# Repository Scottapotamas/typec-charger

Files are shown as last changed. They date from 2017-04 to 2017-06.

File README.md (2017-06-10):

# typec-charger
USB Type C charger for laptops or phones, that uses generic DC inputs as the source.

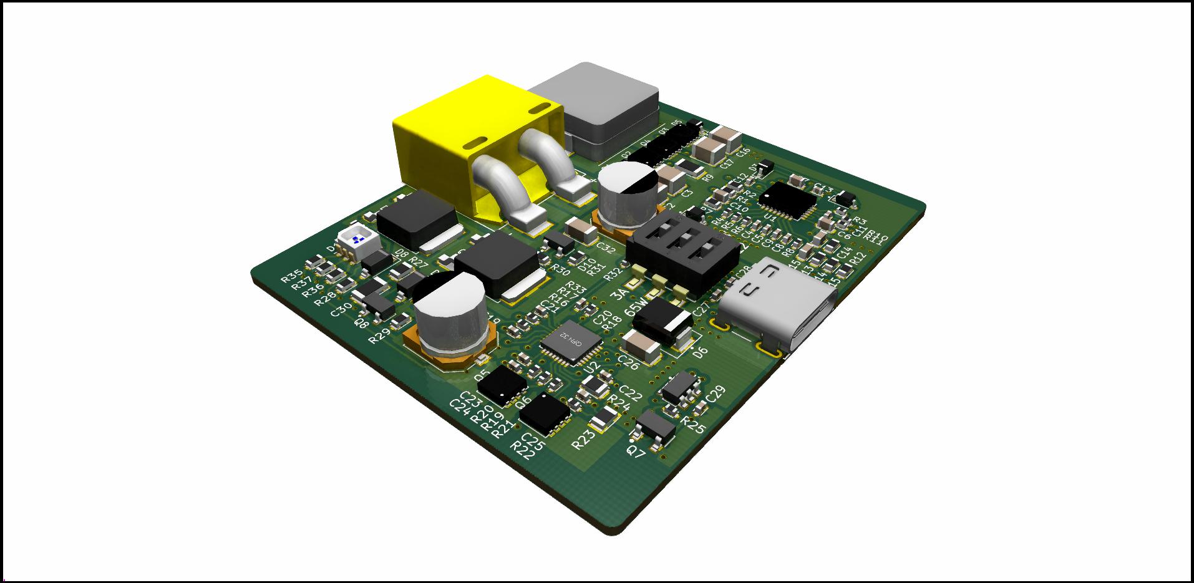
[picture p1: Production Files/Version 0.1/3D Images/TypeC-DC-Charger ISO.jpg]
PCB Iso


# Requirements & Goals

Create a DC-DC charger that uses USBc PD as the delivery mechanism. 
Aim to support the widest range of devices possible (including my Dell XPS 9550).

Run off Li-Poly or Li-Ion cells or similar sources. This could include car batteries (directly or from cigarette lighter socket), and other sources. 
This is useful when taking devices to the field, or allows a comodity pouch cell battery to act as a bulk battery bank.
 
- Accept wide input range sources, 10V to 26V operating input (3S to 6S lithium, includes 12V and 24V automotive).
- Use XT60? input to allow direct lipo connectors or existing COTS cables with aligators etc.

- Input must be ESD protected and filtered.
- Input must have reverse polarity protection, and overvoltage up to 30V DC.
- Device must indicate that a power source has been applied.
- Device should include visual indication that battery is low.
- Device should include battery voltage low-cutoff to prevent over-discharge of source.

- Output USB 3.1 C Power Delivery 2.0 Compliant charging power (5, 9, 12, 20V) at up to 3A. Consider 5A as optional expansion?
- USB Type C socket on the charger, to allow users to find their own cable. No integrated cable tail.
- Compatibility with Dell XPS, Apple Macbook Pro, and other devices.
- Compatibility with USB-C fast charging phones if possible.
- Compatiblity with USB2 charging devices as part of compatibility mode (via 3.1C -> 2.0 MicroB cable).
- It is desirable that the charger supports greater than 60W charging for faster charge on performance laptops.
- Output should be ESD Protected and feature filtering for EMI.

- Where practical, x/y/z dimensions should be minimised for tight form factor.
- The device's enclosure should not exceed 50C at steadystate for a 'full load'.
- The device should not emit any audible noice (coil whine etc) which can be heard in a quite space (<25dB?)
- The product should aim to meet applicable EMC standards (class 2, non-intentional radiator), use spec analyser at work to validate.

Ideally this solution costs less than $100AU (not including charge cable or batteries). This would price it under or around the Apple 61W and 87W chargers, or the Chromebook Pixel 60W charger after importing to AUS. 

- Manufacturing cost of assembled PCB is less than $60USD.
- Manufacturing cost of enclosure less than $20USD.
- Manufacturing cost of packaging (box, manual, etc) less than $5USD.

# Testing and Implementation Notes

- Wide input power supply low voltage cutoff set at just under 9V. This is the extent of low battery protection, not using anything smarter.
- Currently there is no additional 3 or 5V reg, which means there isn't any stable voltage. Any additional circuitry has to either support 5-20V or include regulation.
- Input protection circuit is beefy. Confidence in the charger is important, especially with all the press going on with USBC non-compliant chargers.
- Battery indication led was really hard to get worked out. Uses a SMD led and lightpipe for charging status. Might remove this for production.
- Board has been made as small as possible to fit in the example extrusion.
- Power dissipation for power supply stage is worst case 1.7W between all parts. Worst part is switching fet at 650mW. Consider heatsink or thermal transfer to case?
- Validate thermal performance with thermal camera.
- XT60 connector is too high for normal mounting. Consider using a second PCB to drop the height to the center of the extrusion or a different connector.
- Greater than 3A is supported with switch.
- Power limit set to ~60W default, switch will allow ~90W.
- 5A is possible to be selected without the 90W expansion (5/12V devices)

# Manufacturability

- Board is a 4 layer pcb with single sided population. All parts are SMD.
- Small form factor means small boxes and packaging requirements.
- Consider enclosures 
	- https://www.aliexpress.com/store/product/4-pcs-electronics-aluminum-enclosure-boxes-13-60-50mm-2015-aluminum-powder-coating-project-box-aluminum/1006252_32312473247.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
	- https://www.aliexpress.com/item/1-piece-szomk-aluminum-project-box-100-60-13mm-enclosures-for-electronics-electronic-2014-new-aluminum/32241037210.html

5 Prototype boards have been ordered for PCBA. Cost per board is just under 60USD at current.

# Device Compatibility

- Dell XPS didn't like negotiation stage where eval board sat at 12V for a few hundred milliseconds. Disabling 12V and going from 5->20V works fine.
- Investigate XPS when the 5V and 20V are done by same regulator instead of two-stage.
- Dell XPS will charge on lower currents as long as the charger is advertising at least 60W.
- Haven't been able to get more than 61W draw from the XPS, regardless of BIOS settings.

- Nintendo Switch uses the 15V standard which the main model of this charger is not designed for.
- The Switch will charge with 5V 3A though.
- People in https://www.reddit.com/r/NintendoSwitch/comments/5x948s/answering_your_questions_about_usb_typec/ say that the Switch uses 12V as fallback from 15V.

- Supports BC1.2 charging for legacy USB2 devices at up to 2A.
- Charges phones fine at 10W over a USBC-MicroB cable.
- Should support most phones properly with 5V 3A charging over TypeC.

# Sale Notes

Sell it as a standalone device with the option of adding the following:

- Barrel to XT60 connector
- Barrel to Aligator clips
- Barrel to cigarette lighter
- Barrel to D-Tap
- Barrel to ring terminals?

Device should also include some packaging and a card describing the specifications etc.

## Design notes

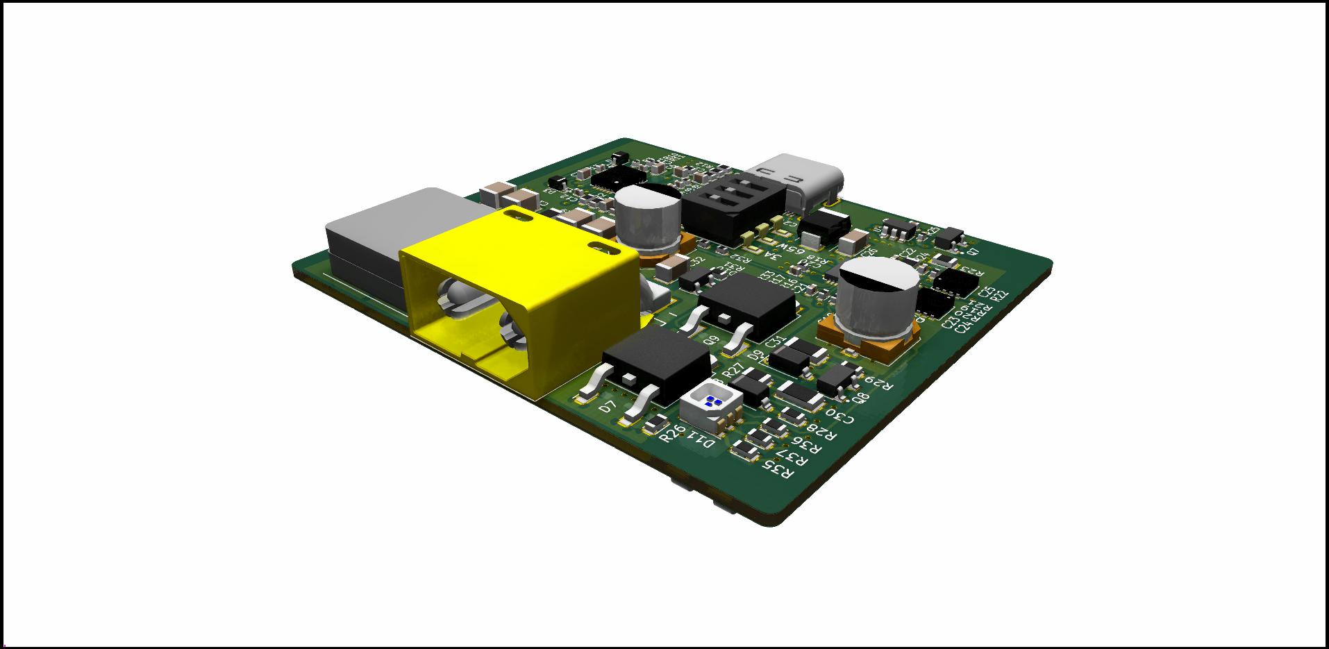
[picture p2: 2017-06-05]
Production Files/Version 0.1/3D Images/TypeC-DC-Charger POWERISO.jpg

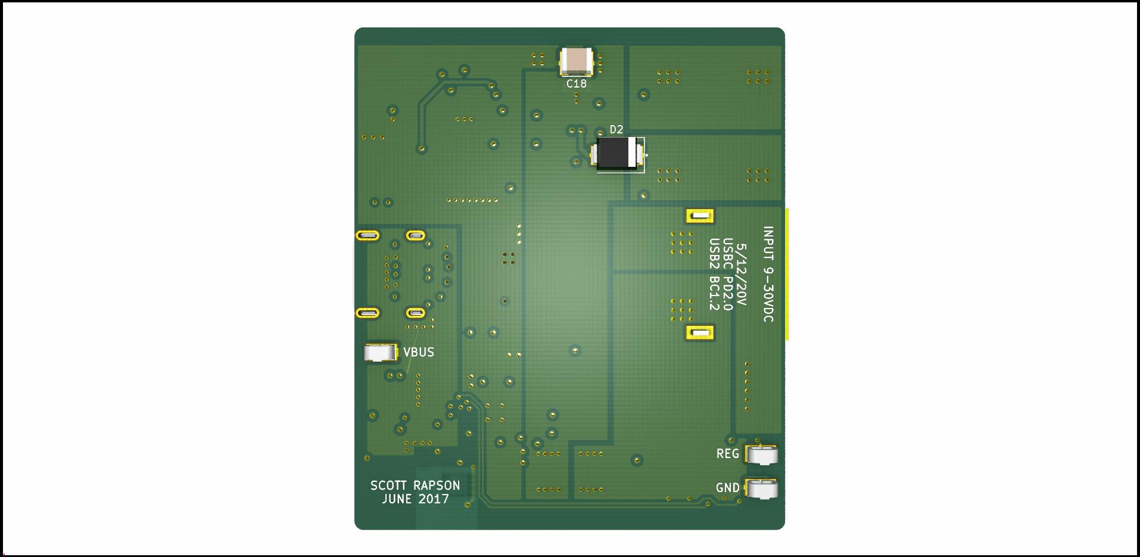
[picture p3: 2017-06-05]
Production Files/Version 0.1/3D Images/TypeC-DC-Charger BOTTOM.jpg

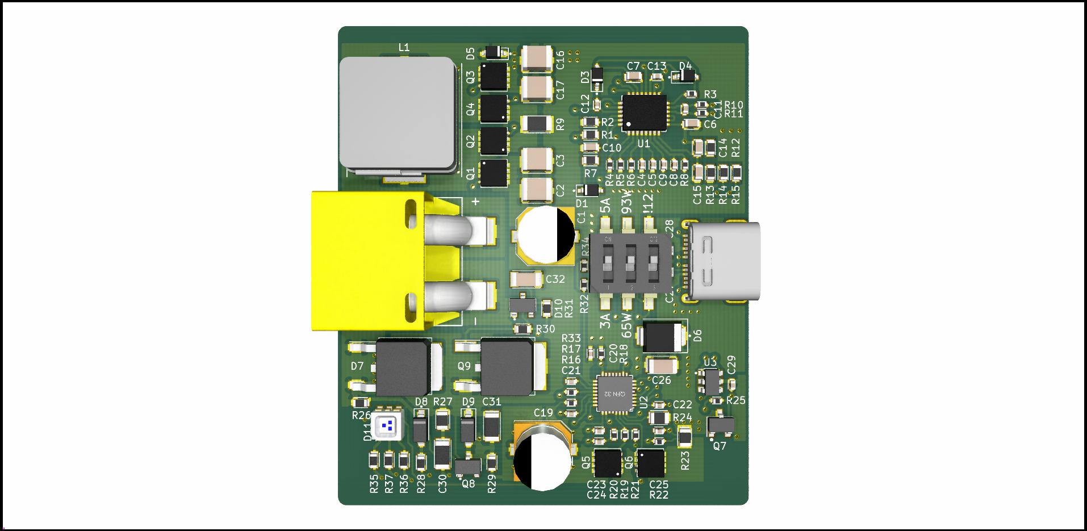
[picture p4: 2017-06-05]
Production Files/Version 0.1/3D Images/TypeC-DC-Charger TOP.jpg

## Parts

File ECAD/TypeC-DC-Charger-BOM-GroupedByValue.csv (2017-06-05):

Title:
Rev:
Source: | C:/Projects/typec-charger/ECAD/TypeC-DC-Charger.sch
Date: | 6/5/2017 10:23:57 AM
Component Count: | 99
Ref | Qty | Value | Description | Manf | Manf# | Installed | Footprint
C1, C19 | 2 | 100UF_ELEC_35V_660X580M | CAP, ALU ELEC, 100UF, 35V, SMD | PANASONIC | EEEFT1V101AP |  | CAPAE660X580DD180L260L
C10, C15 | 2 | 100NF_X7R_1608M | CAP, MLCC, X7R, 100NF, 50V, 0603 | KEMET | C0603C104K5RACAUTO |  | CAPC1608X90L
C11 | 1 | 47PF_X7R_1005M | CAP, MLCC, X7R, 47PF, 50V, C0G, 0402, 1005M | MULTICOMP | MC0402N470K500CT |  | CAPC1005X60L
C14 | 1 | 22NF_X7R_1608M | CAP, MLCC, X7R, 22NF, 50V, 0603, 1608M | MULTICOMP | MC0603B223K500CT |  | CAPC1608X90L
C16, C17, C18 | 3 | 22UF_X7R_3225M | CAP, MLCC, X7R, 22UF, 25V, 10%, 1210, 3225M | MURATA | C1210C226K3RACTU |  | CAPC3225X170L
C2, C3 | 2 | 10UF_X7S_3225M | CAP, MLCC, X7R, 10UF, 50V, 1210 3225M | TDK | C3225X7S1H106M250AB |  | CAPC3225X170L
C20, C25 | 2 | 330NF_X5R_1005M | CAP, MLCC, X5R, 330NF, 25V, 0402, 1005M | TDK | C1005X5R1E334K050BB |  | CAPC1005X60L
C24 | 1 | 10NF_X7R_1005M | CAP, MLCC, X7R, 10NF, 50V, 0402, 1005M | KEMET | C0402C103K5RACTU |  | CAPC1005X60L
C26 | 1 | 6.8UF_X7R_3216M | CAP, MLCC, X7R, 6.8UF, 25V, 1206, 3216M | TDK | C3216X7R1E685K160AB |  | CAPC3216X135L
C27, C28 | 2 | 330PF_X7R_1005M | CAP, MLCC, X7R, 330PF, 50V, 0402, 1005M | MURATA | GRM155R71H331KA01D |  | CAPC1005X60L
C30, C31 | 2 | 1UF_X7R_3216M | CAP, MLCC, X7R, 1UF, 100V, 1206, 3216M | TDK | C3216X7R2A105K160AA |  | RESC3216X60L
C32 | 1 | 100NF_X7R_3216M | CAP, MLCC, X7R, 100nF, 100V, 1206, 3216M | YAGEO | CC1206KKX7R0BB104 |  | CAPC3216X135L
C4, C8 | 2 | 100PF_C0G_1005M | CAP, MLCC, X7R, 100PF, 50V, 0402, 1005M | MURATA | GCM1555C1H101JA16D |  | CAPC1005X60L
C5, C12, C13, C21, C22, C23, C29 | 7 | 100NF_X7R_1005M | CAP, MLCC, X7R, 100NF, 50V, 0402, 1005M | TDK | CGA2B3X7R1H104K050BB |  | CAPC1005X60L
C6, C7 | 2 | 1UF_X7R_1608M | CAP, MLCC, X7R, 1UF, 50V, 0603 | MURATA | GRM188R61H105KAALD |  | CAPC1608X90L
C9 | 1 | 22NF_X7R_1005M | CAP, MLCC, X7R, 22NF, 50V, 0402, 1005M | MURATA | GRM155R71H223KA12D |  | CAPC1005X60L
CON1 | 1 | XT60-PT-MALE | XT60PT, 3.5mm Banana Connector Style, Plug, Male, SMD | AMASS | XT60PT-M |  | XT60-PT-MALE
D1, D3, D4, D5 | 4 | 40V_500mA_SOD323 | DIODE SCHOTTKY 40V 500MA 470mV Fwd SOD323 | NXP | PMEG4005AEA |  | SOD2512X110L
D10 | 1 | BAV99 | DIODE DUAL, 100V, 215mA, 4ns, SOT23 | NXP | BAV99 |  | SOT95P240X110-3L16L
D11 | 1 | LED_RGB_PLCC6 | LED RGB, Osram Opto LRTB GFTM, 470 / 528 / 625 nm, PLCC 6, Rectangle Lens SMD package | OSRAM Opto Semiconductors | LRTB GFTM |  | PLCC110P330X340X200-8L
D2 | 1 | CD214B-B250LF | DIODE, CHIP, 50V, 2A, DO-214AA | BOURNS | CD214B-B250LF |  | SODFL5436X262L
D6 | 1 | SSB44-E3/52T_DO214AA | DIODE, Schottky, 40V, 4A, 10ns, SMB, DO-214AA | VISHAY | SSB44-E3/52T |  | SODFL5436X262L
D7 | 1 | 300V_10A_DPAK | DIODE, 10A cont, 20A, 300V, 13ns, 0.9V, DPAK | ST | STTH1003SBY-TR |  | TO440P972X240-3N
D8, D9 | 2 | 33V_500mW_SOD123 | DIODE, Zener 33V, 500mW, SOD123 | VISAY SEMICONDUCTOR | BAT41ZFILM |  | SOD3715X145L
J1 | 1 | USB_C_SOCKET_RA_SMD | USB Type C Recep, Female, R/A, TOPMNT, GLD Flash, 24 contact, 5A | Molex | 105450-0101 |  | MOLEX-105450-0101
L1 | 1 | 3.3uH_5050M | IHLP5050EZ, INDUCTOR, 3.3UH, 15A, Shielded, 0.0092ohm, 20%, | VISHAY | IHLP5050EZER3R3M01 |  | INDM132129X500N
Q1, Q2 | 2 | CSD18543Q3A | POWER MOSFET, N-CH, NexFET, 60Vds, 20Vgs, 35A, 8.1mOhm, 1.7nC gd, 2.0Vgs, SON | TI | CSD18543Q3A |  | SON65P315X300X90-9T174X245L
Q3, Q4 | 2 | CSD17551Q3A | POWER MOSFET, N-CH, NexFET, 30Vds, 20Vgs, 20A, 7.8mOhm, 1.5nC gd, 1.6Vgs, SON | TI | CSD17551Q3A |  | SON65P315X300X90-9T174X245L
Q5, Q6 | 2 | CSD17579Q3A | POWER MOSFET, N-CH, NexFET, 30Vds, 20Vgs, 20A, 8.7mOhm, 1.2nC gd, 1.5Vgs, SON | TI | CSD17579Q3A |  | SON65P315X300X90-9T174X245L
Q7 | 1 | 2N7002P | MOSFET N-CH 60V 0.36A SOT-23 | Fairchild | 2N7002,215 |  | SOT95P240X110-3L16N
Q8 | 1 | BC857B | Transistor, PNP 45V, 100mA, 250mW, SOT23 | MULTICOMP | BC857B |  | SOT95P240X110-3L16L
Q9 | 1 | IRFR9024NTRPBF | MOSFET P-CH 55V 11A DPAK TO-252AA | Infineon | IRFR9024NTRPBF |  | DPAK4P229_990X239L159X95L
R1 | 1 | 249K_1608M | RESISTOR, THICK FILM, 249K, 100mW, 1%, 0603, 1608M | VISHAY | CRCW0603249KFKEA |  | RESC1608X50L
R10, R11 | 2 | 100R_1005M | RESISTOR, THICK FILM, 100R, 63mW, 1%, 0402, 1005M | VISHAY | CRCW0402100RFKED |  | RESC1005X40L
R12 | 1 | 49K9_1608M | RESISTOR, THICK FILM, 49.9K, 100mW, 1%, 0603, 1608M | VISHAY | CRCW060349K9FKEA |  | RESC1608X50L
R13 | 1 | 9K53_1608M | RESISTOR, THICK FILM, 9.53K, 100mW, 1%, 0603, 1608M | VISHAY | CRCW06039K53FKEA |  | RESC1608X50L
R14 | 1 | 4K99_1608M | RESISTOR, THICK FILM, 4.99K, 100mW, 1%, 0603, 1608M | VISHAY | MCT06030C4991FP500 |  | RESC1608X50L
R15 | 1 | 5K76_1608M | RESISTOR, THICK FILM, 5.76K, 100mW, 1%, 0603, 1608M | PANASONIC | ERJ3EKF5761V |  | RESC1608X50L
R16 | 1 | 1M_1005M | RESISTOR, THICK FILM, 1MOhm, 63mW, 1%, 0402, 1005M | VISHAY | CRCW04021M00FKED |  | RESC1005X40L
R17 | 1 | 680K_1005M | RESISTOR, THICK FILM, 680K, 100mW, 1%, 0402, 1005M | PANASONIC | ERJ2RKF6803X |  | RESC1005X40L
R18 | 1 | 100K_1005M | RESISTOR, THICK FILM, 100K, 100mW, 1%, 0402, 1005M | PANASONIC | ERJ2RKF1003X |  | RESC1005X40L
R19, R21, R22, R25 | 4 | 10R_1005M | RESISTOR, THICK FILM, 10R, 63mW, 1%, 0402, 1005M | VISHAY | CRCW040210R0FKED |  | RESC1005X40L
R2 | 1 | 41K2_1608M | RESISTOR, THICK FILM, 41.2K, 200mW, 0603, 1608M | PANASONIC | ERJP03F4122V |  | RESC1608X50L
R20 | 1 | 1K_1005M | RESISTOR, THICK FILM, 1K, 63mW, 1%, 0402, 1005M | VISHAY | CRCW04021K00FKED |  | RESC1005X40L
R23 | 1 | 0.005R_2012M | RESISTOR, THICK FILM, 5mOhm, 500mW, 1%, 0805, 2012M | WALSIN | WW08RR005FTL |  | RESC2012X50L
R24 | 1 | 120R_2012M | RESISTOR, THICK FILM, 120R, 500mW, 5%, 0805, 2012M | PANASONIC | ERJ-P06J121V |  | RESC2012X50L
R26 | 1 | 100K_1608M | RESISTOR, THICK FILM, 100K, 125mW, 1%, 0603, 1608M | MULTICOMP | MC0063W06035100K |  | RESC1608X50L
R27 | 1 | 10R_2012M | RESISTOR, THICK FILM, 10R, 125mW, 1%, 0805, 2012M | PANASONIC | ERJ8ENF10R0V |  | RESC2012X50L
R28 | 1 | 22K_1608M | RESISTOR, THICK FILM, 22K, 100mW, 1%, 0603, 1608M | MULTICOMP | MCMR06X2202FTL |  | RESC1608X50L
R29 | 1 | 332K_1608M | RESISTOR, THICK FILM, 332K, 250mW, 0603, 1608M | PANASONIC | ERJPA3F3323V |  | RESC1608X50L
R3, R8 | 2 | 10K_1005M | RESISTOR, THICK FILM, 10K, 63mW, 1%, 0402, 1005M | VISHAY | CRCW040210K0FKED |  | RESC1005X40L
R31 | 1 | 10K0_1608M | RESISTOR, THICK FILM, 10K, 125mW, 1%, 0603, 1608M | TE CONNECTIVITY | CRGH0603F10K |  | RESC1608X50L
R32, R34 | 2 | 220K_1005M | RESISTOR, THICK FILM, 220K, 63mW, 1%, 0402, 1005M | MULTICOMP | MC00625W04021220K |  | RESC1005X40L
R33 | 1 | 0R_1005M | RESISTOR, THICK FILM, 0R, 63mW, 1%, 0402, 1005M | VISHAY | CRCW04020000Z0ED |  | CAPC1005X60L
R35 | 1 | 1K50_1608M | RESISTOR, THICK FILM, 1K5, 100mW, 1%, 0603, 1608M | MULTICOMP | MCSR06X1501FTL |  | RESC1608X50L
R36 | 1 | 2K40_1608M | RESISTOR, THICK FILM, 2K4, 63mW, 1%, 0603, 1608M | MULTICOMP | MC0063W060312K4 |  | RESC1608X50L
R37 | 1 | 330R_1608M | RESISTOR, THICK FILM, 330R, 100mW, 1%, 0603, 1608M | VISHAY DRALORIC | CRCW0603330RFKEA |  | RESC1608X50L
R4 | 1 | 93K1_1005M | RESISTOR, THICK FILM, 93.1K, 100mW, 1%, 0402, 1005M | PANASONIC | ERJ2RKF9312X |  | RESC1005X40L
R5 | 1 | 0R_1005M | RESISTOR, THICK FILM, 0R, 63mW, 1%, 0402, 1005M | VISHAY | CRCW04020000Z0ED |  | RESC1005X40L
R6 | 1 | 84K5_1005M | RESISTOR, THICK FILM, 84.5K, 63mW, 1%, 0402, 1005M | PANASONIC | ERA2AEB8452X |  | RESC1005X40L
R7, R30 | 2 | 10R_1608M | RESISTOR, THICK FILM, 10R, 125mW, 0603, 1608M | MULTICOMP | MCHP03W8F100JT5E |  | RESC1608X50L
R9 | 1 | 0.01R_3216M | RESISTOR, THICK FILM, 10mOhm, 1W, 1206, 3216M | Vishay | WSLP1206R0100FEA |  | RESC3216X60L
SW1 | 1 | 2.54mm_3xSPST_SMD | DIP/SIP Switch, 3 Circuits, SPST, SMD, DIP Sealed, 24 VDC | MULTICOMP | MCEMR-03-T |  | MCEMR-03-T
TEST2, TEST3, TEST5 | 3 | PROBE_HOOK | PCB Probe Hook SMD | HARWIN | S1751-46R |  | HARWIN_S1751-46
U1 | 1 | LM5175RHF | 4-Switch Synchronous Buck-Boost Controller, 3.5-42V IN, 0.8-55V OUT, <600kHz, VQFN-28 | TEXAS INSTRUMENTS | LM5175RHFR |  | QFN50P500X400X100-29T255X355N
U2 | 1 | TPS25741 | USB 3.1 Type C and USB PD 2.0 Delivery Port Control IC, 5/12/20V 15-100W, internal 1.8V 35mA, QFN 32 with pad | TEXAS INSTRUMENTS | TPS24741 |  | QFN40P400X400X100-33T280N
U3 | 1 | TPS2514 | TPS251xx USB, Dedicated Charging Port Controller, BC1.2 auto detect, SOT23-6 | TI | TPS2514DBVR |  | SOT95P240X110-6L16L
Tool: | Eeschema (2016-11-21 revision f7cc0a9)-makepkg
Script: | C:\Projects\ECAD\kicad-scripts\BOM\bom\BOM-GroupedByValue.py

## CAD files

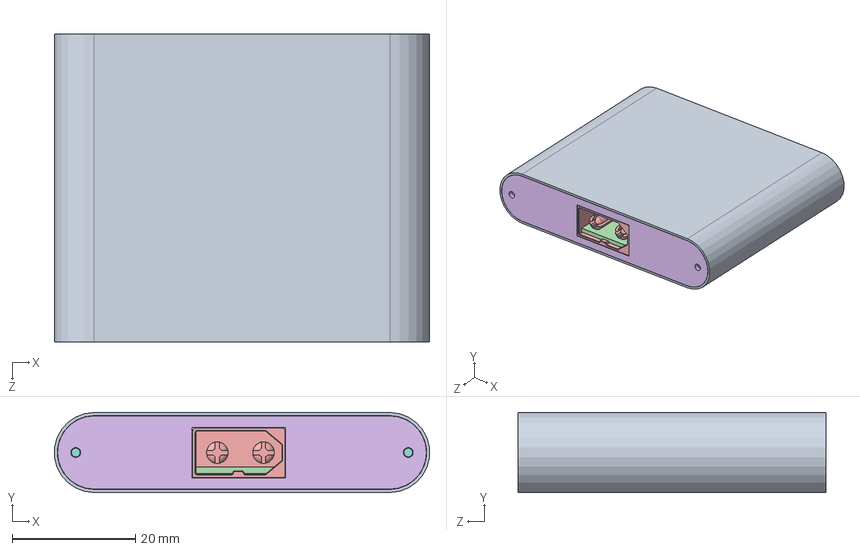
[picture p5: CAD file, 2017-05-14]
MCAD/Assembled Product.SLDASM
60.9 x 13.0 x 50.0 mm
Enclosure Extrusion Concept 1 short
Enclosure Extrusion Concept 1 End Power
Enclosure Extrusion Concept 1 End USB
Bolt Mockup x 2

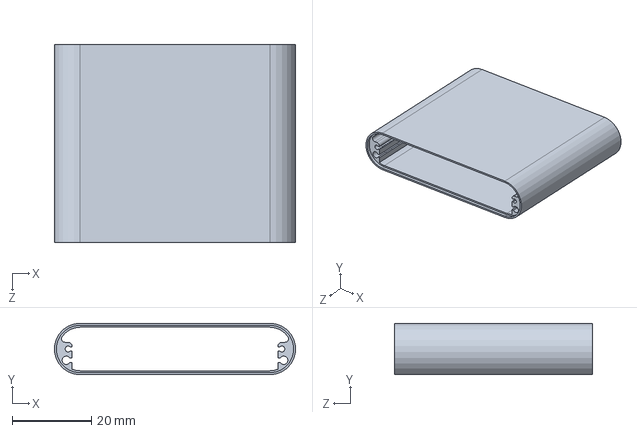
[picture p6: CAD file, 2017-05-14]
MCAD/Enclosure Extrusion Concept 1 short.SLDPRT
60.9 x 13.0 x 50.0 mm

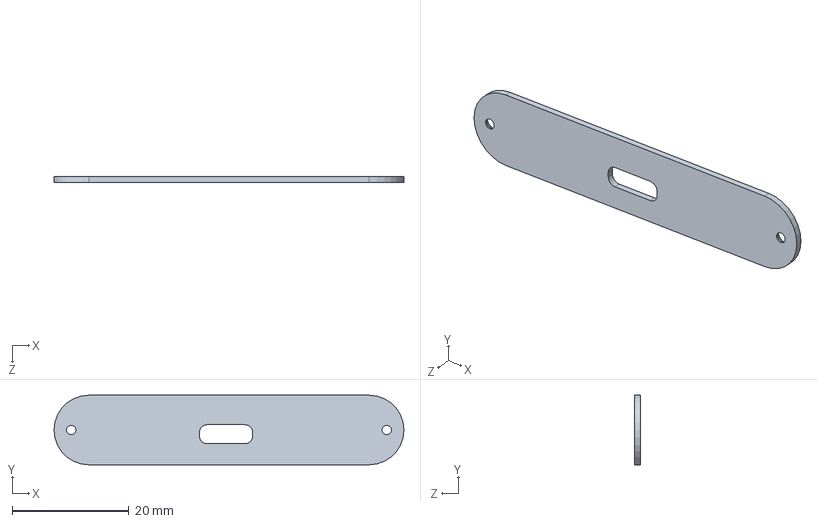
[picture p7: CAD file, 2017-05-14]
MCAD/Enclosure Extrusion Concept 1 End USB.SLDPRT
59.9 x 11.9 x 1.00 mm

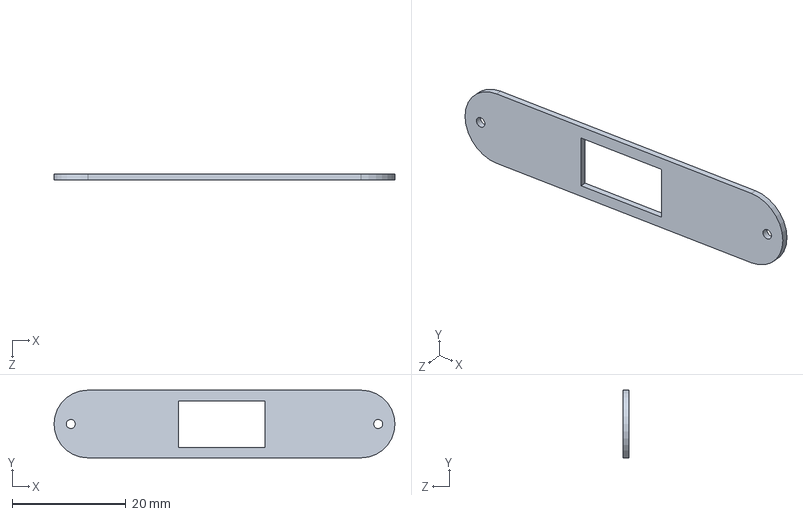
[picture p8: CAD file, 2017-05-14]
MCAD/Enclosure Extrusion Concept 1 End Power.SLDPRT
59.9 x 11.9 x 1.00 mm

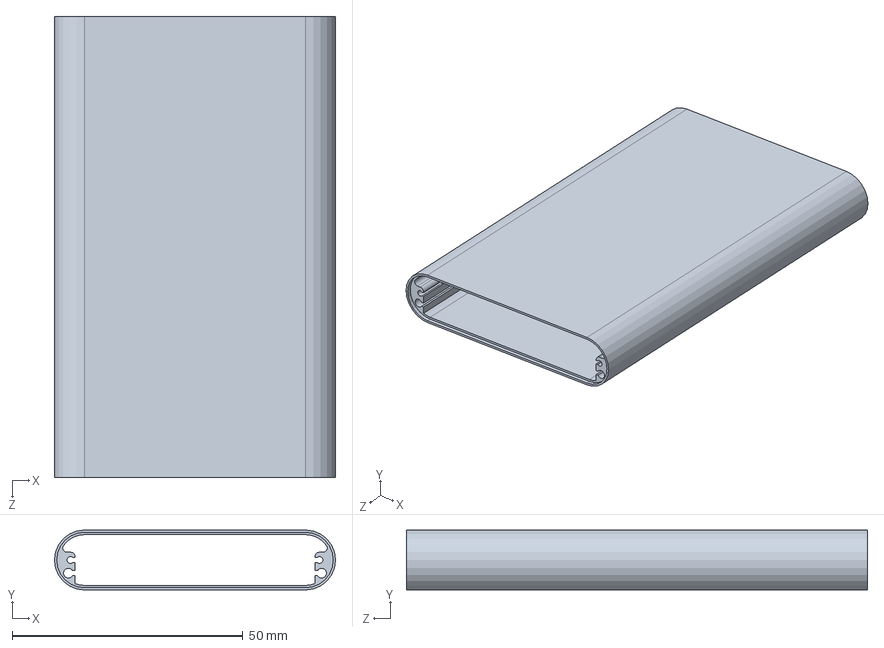
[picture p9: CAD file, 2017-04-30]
MCAD/Enclosure Extrusion Concept 1.SLDPRT
61.0 x 13.0 x 100.0 mm

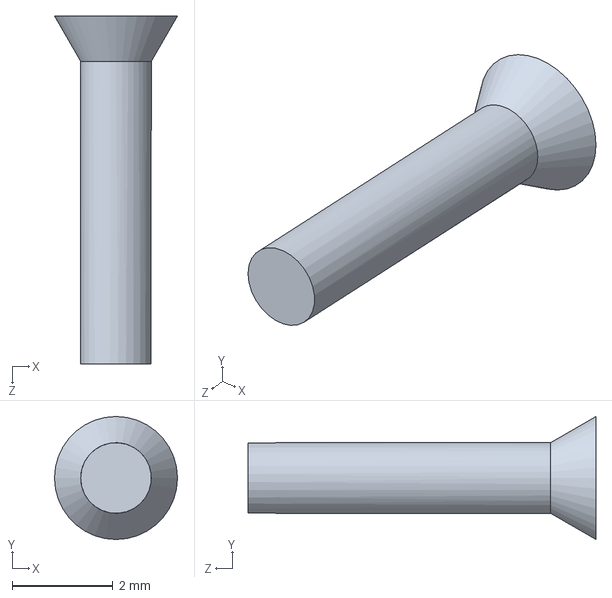
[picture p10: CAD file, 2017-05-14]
MCAD/Bolt Mockup.SLDPRT
2.44 x 2.44 x 6.90 mm

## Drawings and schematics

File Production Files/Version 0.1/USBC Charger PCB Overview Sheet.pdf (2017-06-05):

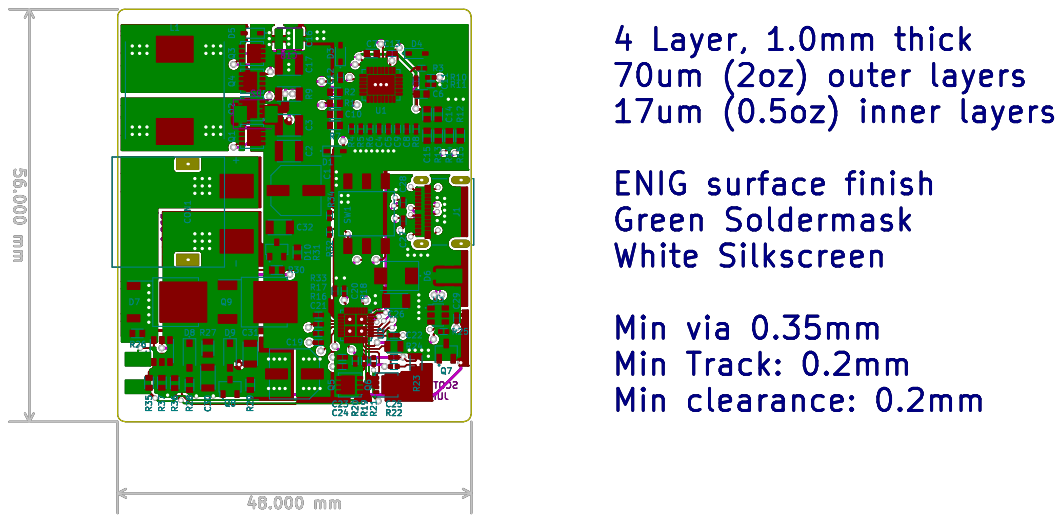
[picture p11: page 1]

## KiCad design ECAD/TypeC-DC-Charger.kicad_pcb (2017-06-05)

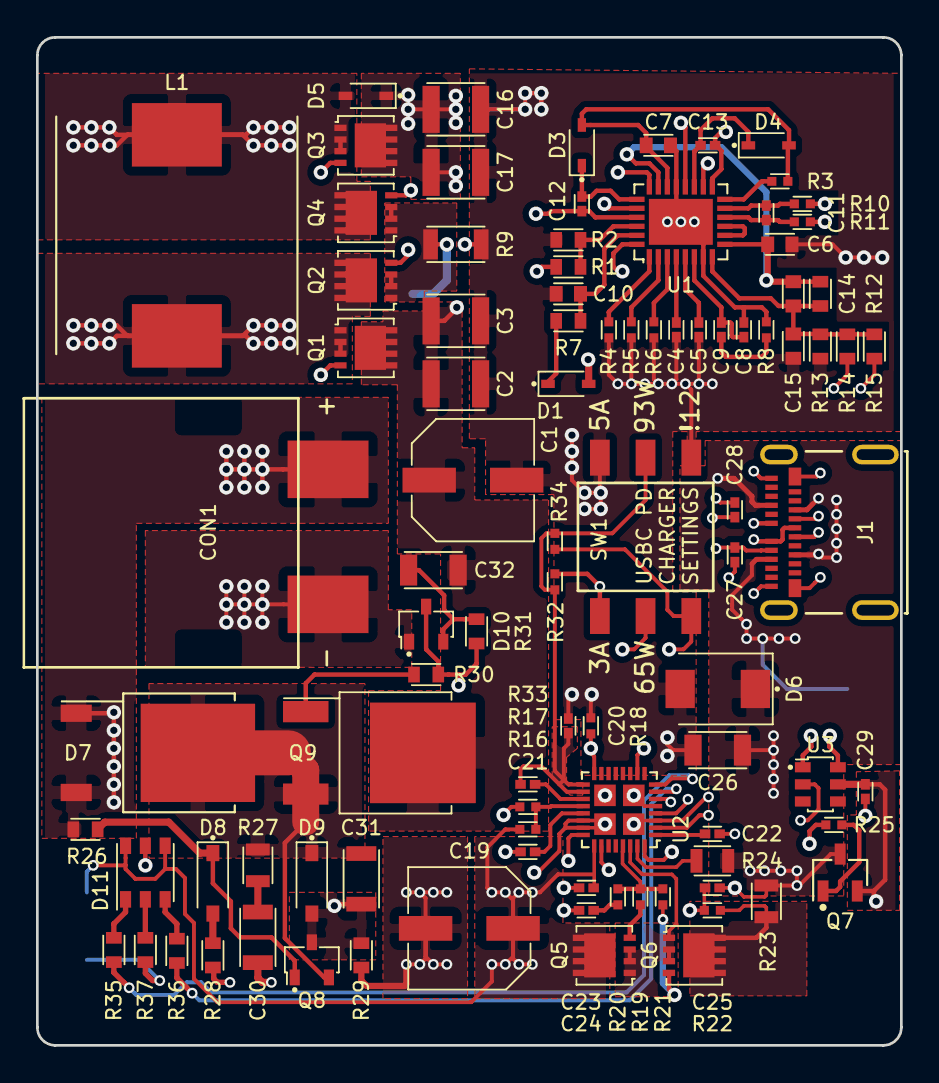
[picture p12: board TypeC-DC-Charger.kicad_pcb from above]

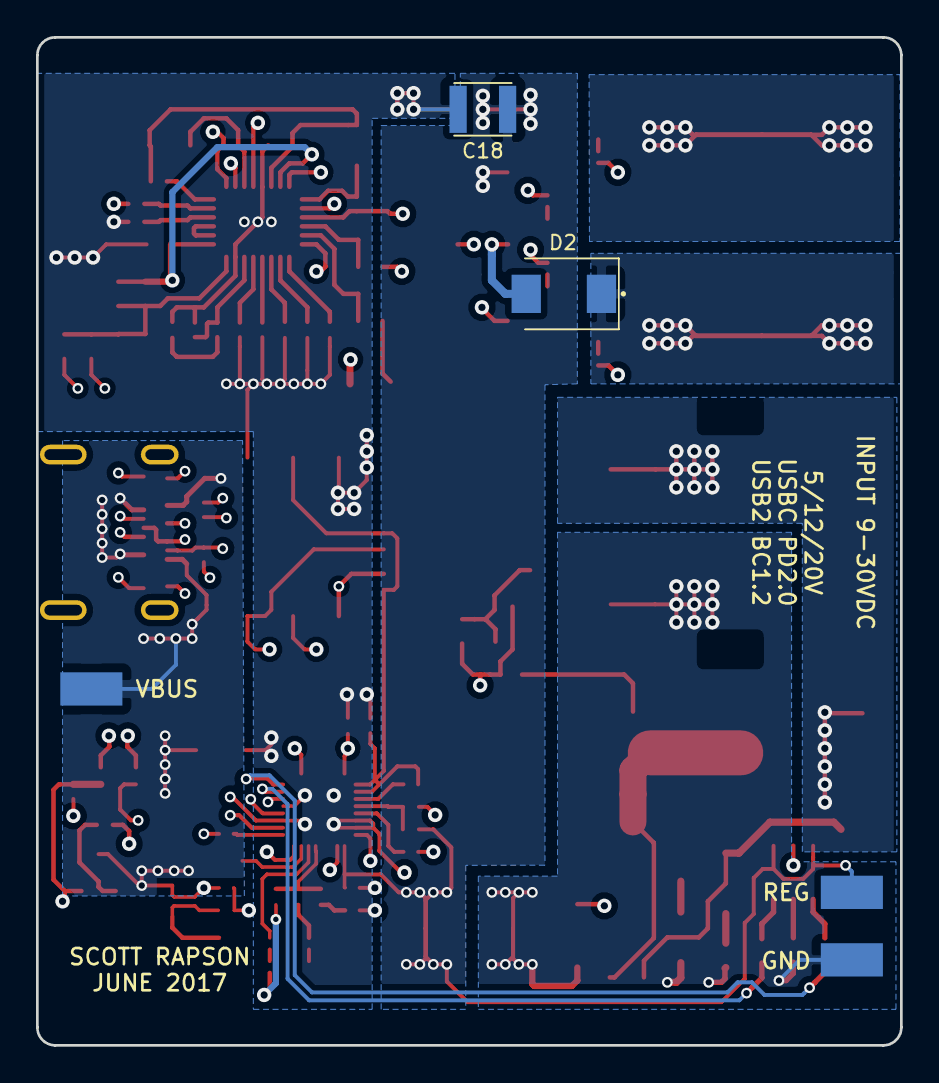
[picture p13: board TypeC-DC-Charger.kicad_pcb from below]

Board: 4 copper layers, 48.0 x 56.0 mm, 99 parts (5 on the bottom side), 65 nets.

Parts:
C1, C19: 100UF_ELEC_35V_660X580M; CAPAE660X580DD180L260L
C2, C3: 10UF_X7S_3225M; CAPC3225X170L
C4, C8: 100PF_C0G_1005M; CAPC1005X60L
C5, C12, C13, C21, C22, C23, C29: 100NF_X7R_1005M; CAPC1005X60L
C6, C7: 1UF_X7R_1608M; CAPC1608X90L
C9: 22NF_X7R_1005M; CAPC1005X60L
C10, C15: 100NF_X7R_1608M; CAPC1608X90L
C11: 47PF_X7R_1005M; CAPC1005X60L
C14: 22NF_X7R_1608M; CAPC1608X90L
C16, C17, C18: 22UF_X7R_3225M; CAPC3225X170L
C20, C25: 330NF_X5R_1005M; CAPC1005X60L
C24: 10NF_X7R_1005M; CAPC1005X60L
C26: 6.8UF_X7R_3216M; CAPC3216X135L
C27, C28: 330PF_X7R_1005M; CAPC1005X60L
C30, C31: 1UF_X7R_3216M; RESC3216X60L
C32: 100NF_X7R_3216M; CAPC3216X135L
CON1: XT60-PT-MALE
D1, D3, D4, D5: 40V_500mA_SOD323; SOD2512X110L
D2: CD214B-B250LF; SODFL5436X262L
D6: SSB44-E3/52T_DO214AA; SODFL5436X262L
D7: 300V_10A_DPAK; TO440P972X240-3N
D8, D9: 33V_500mW_SOD123; SOD3715X145L
D10: BAV99; SOT95P240X110-3L16L
D11: LED_RGB_PLCC6; PLCC110P330X340X200-8L
J1: USB_C_SOCKET_RA_SMD; MOLEX-105450-0101
L1: 3.3uH_5050M; INDM132129X500N
Q1, Q2: CSD18543Q3A; SON65P315X300X90-9T174X245L
Q3, Q4: CSD17551Q3A; SON65P315X300X90-9T174X245L
Q5, Q6: CSD17579Q3A; SON65P315X300X90-9T174X245L
Q7: 2N7002P; SOT95P240X110-3L16N
Q8: BC857B; SOT95P240X110-3L16L
Q9: IRFR9024NTRPBF; DPAK4P229_990X239L159X95L
R1: 249K_1608M; RESC1608X50L
R2: 41K2_1608M; RESC1608X50L
R3, R8: 10K_1005M; RESC1005X40L
R4: 93K1_1005M; RESC1005X40L
R5: 0R_1005M; RESC1005X40L
R6: 84K5_1005M; RESC1005X40L
R7, R30: 10R_1608M; RESC1608X50L
R9: 0.01R_3216M; RESC3216X60L
R10, R11: 100R_1005M; RESC1005X40L
R12: 49K9_1608M; RESC1608X50L
R13: 9K53_1608M; RESC1608X50L
R14: 4K99_1608M; RESC1608X50L
R15: 5K76_1608M; RESC1608X50L
R16: 1M_1005M; RESC1005X40L
R17: 680K_1005M; RESC1005X40L
R18: 100K_1005M; RESC1005X40L
R19, R21, R22, R25: 10R_1005M; RESC1005X40L
R20: 1K_1005M; RESC1005X40L
R23: 0.005R_2012M; RESC2012X50L
R24: 120R_2012M; RESC2012X50L
R26: 100K_1608M; RESC1608X50L
R27: 10R_2012M; RESC2012X50L
R28: 22K_1608M; RESC1608X50L
R29: 332K_1608M; RESC1608X50L
R31: 10K0_1608M; RESC1608X50L
R32, R34: 220K_1005M; RESC1005X40L
R33: 0R_1005M; CAPC1005X60L
R35: 1K50_1608M; RESC1608X50L
R36: 2K40_1608M; RESC1608X50L
R37: 330R_1608M; RESC1608X50L
SW1: 2.54mm_3xSPST_SMD; MCEMR-03-T
TEST2, TEST3, TEST5: PROBE_HOOK; HARWIN_S1751-46
U1: LM5175RHF; QFN50P500X400X100-29T255X355N
U2: TPS25741; QFN40P400X400X100-33T280N
U3: TPS2514; SOT95P240X110-6L16L

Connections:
5V: C29.1, D11.A2, Q7.2, U3.5
/Connectors/RAW_BATT: CON1.2, D7.A, R26.2
/Power Supply/VCC: C7.1, D3.A, D4.A, R3.2, U1.20
/USBC Controller/DVDD: C20.1, R32.1, R33.1, R34.1, SW1.4, U2.17, U2.18
/USBC Controller/EN12V: R34.2, SW1.5, U2.10
/USBC Controller/HIPWR: R32.2, SW1.1, U2.6
/USBC Controller/PSEL: R18.2, SW1.3, U2.16
CC1: C27.1, J1.A5, U2.2
CC2: C28.1, J1.B5, U2.4
CTRL1: R14.2, R36.2, U2.7
CTRL2: R15.2, R35.2, U2.8
D+: J1.A6, J1.B6, U3.1
D-: J1.A7, J1.B7, U3.6
DSCG: R24.2, U2.31
FB: C14.2, C15.1, R12.2, R13.1, R14.1, R15.1, U1.8
G5V: R25.2, U2.32
GDNG: R19.2, R20.1, R21.2, U2.29
GDNS: Q5.2, Q6.2, U2.30
GND: C1.2, C2.2, C3.2, C4.2, C5.2, C6.2, C7.2, C8.2, C10.1, C15.2, C16.2, C17.2, C18.2, C19.2, C20.2, C21.2, C22.2, C23.2, C24.2, C26.2, C27.2, C28.2, C29.2, C30.2, CON1.1, D6.A, D10.1, J1.A1, J1.A12, J1.B1, J1.B12, J1.S1, J1.S2, J1.S3, J1.S4, R2.2, R4.2, R5.2, R6.2, R8.2, R9.1, R11.1, R13.2, R17.2, R18.1, R28.2, R29.2, R37.2, SW1.2, SW1.6, TEST5.1, U1.7, U1.19, U1.29, U2.3, U2.5, U2.22, U2.23, U2.33, U3.2
HDRV1: Q1.1, U1.24
HDRV2: Q3.1, U1.16
ISNS: C25.1, R22.2, U2.24
LDRV1: Q2.1, U1.22
LDRV2: Q4.1, U1.18
unnamed: C4.1, U1.4
unnamed: C5.1, U1.5
unnamed: C8.1, C9.1, U1.6
unnamed: C9.2, R8.1
unnamed: C10.2, R7.2, U1.27
unnamed: C11.1, R10.2, U1.13
unnamed: C11.2, R11.2, U1.12
unnamed: C12.1, D3.C, U1.23
unnamed: C13.1, D4.C, U1.17
unnamed: C21.1, U2.21
unnamed: C22.1, U2.1
unnamed: C24.1, R20.2
unnamed: C30.1, R27.2
unnamed: C31.1, D7.C, D9.C, Q8.2, Q9.3, R27.1
unnamed: C31.2, D9.A, D10.3, Q8.3, R29.1, R30.2, R31.2
unnamed: C32.2, D10.2, R31.1
unnamed: D1.C, R7.1
unnamed: D8.A, R28.1
unnamed: D8.C, Q8.1, R26.1
unnamed: D11.C1, R35.1
unnamed: D11.C2, R37.1
unnamed: D11.C3, R36.1
unnamed: Q5.1, R19.1
unnamed: Q6.1, R21.1
unnamed: Q6.3, R22.1, R23.2
unnamed: Q7.1, R25.1
unnamed: Q9.1, R30.1
unnamed: R1.2, R2.1, U1.26
unnamed: R3.1, U1.14
unnamed: R4.1, U1.1
unnamed: R5.1, U1.2
unnamed: R6.1, U1.3
unnamed: R16.2, R17.1, U2.20
unnamed: R33.2, U2.19
unnamed: U1.10, U1.11
RCS: D2.A, Q2.2, Q4.2, R9.2, R10.1
SW1: C12.2, D2.C, L1.2, Q1.2, Q2.3, U1.25
SW2: C13.2, D5.A, L1.1, Q3.2, Q4.3, U1.15
VARIABLE_DC: C6.1, C14.1, C16.1, C17.1, C18.1, C19.1, C23.1, D5.C, D11.A1, D11.A3, Q3.3, Q5.3, R12.1, R16.1, TEST2.1, U1.9, U1.21, U2.25
VBUS: C25.2, C26.1, D6.C, J1.A4, J1.A9, J1.B4, J1.B9, Q7.3, R23.1, R24.1, TEST3.1, U2.26
VIN: C1.1, C2.1, C3.1, C32.1, D1.A, Q1.3, Q9.4, R1.1, U1.28

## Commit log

2017-04-22 KiCAD project creation. Added USBC charge IC, connector, and regulator IC
    [TypeC-DC-Charger.kicad_pcb, TypeC-DC-Charger.sch]
2017-04-25 Started building out required parts and began wiring schematic.
    [TypeC-DC-Charger.sch]
2017-04-25 Schematic development for charger and usbc hardware
    [TypeC-DC-Charger.sch]
2017-04-29 Drew aluminium extrusion profile currently under consideration
    [Enclosure Extrusion Concept 1.SLDPRT]
2017-04-29 Split schematic into multiple sheets, added remaining regulator parts, cleanups and other additions.
    [Connector.sch, PD Controller.sch, PowerSupply.sch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]
2017-04-29 Additional cleanup and misc notes
    [Connector.sch, PD Controller.sch, PowerSupply.sch]
2017-04-30 Added shorter 50mm version of extrusion model as board looks like it could fit
    [Enclosure Extrusion Concept 1.SLDPRT]
2017-04-30 Soft start circuit, Switched BC1.2 IC, more 0402 parts now, placement and routing.
    [Connector.sch, PD Controller.sch, PowerSupply.sch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]
2017-04-30 Update to soft start circuit
    [Connector.sch]
2017-05-01 Changed some parts to 0402, routing and pour improvements
    [Connector.sch, PD Controller.sch, TypeC-DC-Charger.kicad_pcb]
2017-05-04 Added better input protection with soft start, over voltage protection, cap discharge etc. Fixed some part selections, reformatting in schematic. Placement of input protection circuit. Cleanup of PCB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
    [Connector.sch, Status Light.sch, TypeC-DC-Charger-BOM-GroupedByValue.csv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]
2017-05-04 Fixed some newer designator labels incorrect font size
    [TypeC-DC-Charger.kicad_pcb]
2017-05-04 Updated readme with current thoughts
2017-05-07 Added dip switch selection to charge settings. PCB placement improvements. Added 3mm led placeholder for indicator led.
    [Connector.sch, PD Controller.sch, Status Light.sch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]
2017-05-07 Silkscreen text for dip switches, part placement improvements.
    [PD Controller.sch, TypeC-DC-Charger.kicad_pcb]
2017-05-14 Added left over cad files
    [Assembled Product.SLDASM, Bolt Mockup.SLDPRT, Enclosure Extrusion Concept 1 End Power.SLDPRT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]
2017-05-21 Updated pcb files
    [Connector.sch, PD Controller.sch, PowerSupply.sch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]
2017-05-22 Adding vias on thermal planes
    [TypeC-DC-Charger.kicad_pcb]
2017-05-22 Vias and power supply signal routing
    [TypeC-DC-Charger.kicad_pcb]
2017-05-22 Routing signals and more power planes and misc
    [TypeC-DC-Charger.kicad_pcb]
2017-05-23 RGB led added. Routing and pours. Removed some DRC errors, fixed cosmetics.
    [Connector.sch, Status Light.sch, TypeC-DC-Charger.kicad_pcb]
2017-05-30 Updates to schematic and pcb (led and routing)
    [Status Light.sch, TypeC-DC-Charger.kicad_pcb]
2017-05-31 Routing and fixed dip switch disassociated footprint
    [Connector.sch, PD Controller.sch, PowerSupply.sch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]
2017-05-31 RGB led final schematic drawing and prelim resistor selection. Routing and misc board level changes.
    [Connector.sch, PD Controller.sch, PowerSupply.sch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]
2017-05-31 Routing and cosmetics
    [TypeC-DC-Charger.kicad_pcb]
2017-06-01 Routing improvements. Silkscreen text and dimensions added. General review of placement and fixes as found.
    [TypeC-DC-Charger.kicad_pcb]
2017-06-03 Planes, improving pours and routing. Obsessing over small details.
    [TypeC-DC-Charger.kicad_pcb]
2017-06-03 Finishing touches for pcb
    [TypeC-DC-Charger.kicad_pcb]
2017-06-05 Added Production outputs
    [TypeC-DC-Charger-BOM-GroupedByValue.csv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]
2017-06-05 PCB title block text
    [TypeC-DC-Charger.kicad_pcb, TypeC-DC-Charger.sch]
